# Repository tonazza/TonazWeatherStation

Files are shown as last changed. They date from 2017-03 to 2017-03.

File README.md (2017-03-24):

# TonazWeatherStation
Indoor weather station based on Raspberry Pi 2 model B

**2017/3/24**

Initial upload of the files.
Still NOT working, just a work in progress.

**PROJECT DESCRIPTION**

This is a Weather Station, conceived for measuring air properties in an indoor environment.

The main components are:

**Raspberry Pi 2 Model B** Single board computer

https://www.raspberrypi.org/products/raspberry-pi-2-model-b/

**MIDAS MC21605G12W-VNMLWI** LCD 16x2 chars I2C module, white on black

http://it.farnell.com/midas/mc21605g12w-vnmlwi/lcd-alpha-num-16-x-2-white/dp/2425704

**HONEYWELL HIH8131-000-001** humidity and temperature sensor

http://www.mouser.it/Search/ProductDetail.aspx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

**MEASUREMENT SPECIALTIES MS580502BA01-50** barometric pressure sensor

http://www.mouser.it/Search/ProductDetail.aspx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

The hardware project(Pi HAT + connection boards) was made using EAGLE CAD 6.5.

The software was made in Python 3, to be run on the Raspberry Pi equipped with Raspbian minimal on a 4GB uSD card.

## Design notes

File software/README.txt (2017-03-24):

TONAZ_WEATHER_STATION - NEEDED PACKAGES FOR  PYTHON 3 SOFTWARE

sudo apt-get install python3 python3-dev python3-smbus python3-pip i2c-tools python3-spidev
sudo python3 -m pip install RPi.GPIO

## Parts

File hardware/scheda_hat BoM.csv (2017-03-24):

Part | Value | Device | Package | Description | 3D_PACKAGE | DESCRIPTION | HEIGHT | MANUFACTURER_NAME | MANUFACTURER_PART_NUMBER | MF | MPN | OC_FARNELL | OC_NEWARK | PACKAGE | RS_PART_NUMBER | SUPPLIER | SUPPLIER_NAME
C1 | 100n | C-EUC0805K | C0805K | CAPACITOR, European symbol
C2 | 1u | C-EUC0805K | C0805K | CAPACITOR, European symbol
C3 | 100n | C-EUC0805K | C0805K | CAPACITOR, European symbol
IC1 | HIH8131-000-001 | HIH8131-000-001 | SOIC127P600X220-8N | Honeywell HIH8131-000-001 Humidity Sensor 8-Pin SOIC, -40 +125 C |  | Honeywell HIH8131-000-001 Humidity Sensor 8-Pin SOIC, -40 +125 C | 2.2mm | Honeywell | HIH8131-000-001 |  |  |  |  |  | 8748744 |  | RS
IC2 | MS5805-02BA01 | MS5805-02BA01 | MS5805-02BA | Absolute Pressure Sensor
J3 | LCD MIDAS MC21605G12W | PINHD-1X16 | 1X16 | PIN HEADER
Q1 | FDN337N | FDN337N | SOT95P230X110-3N | N-channel MOSFET |  |  |  |  |  |  | FDN337N | 9845356 |  | SOT-23 |  | Fairchild
Q2 | FDN337N | FDN337N | SOT95P230X110-3N | N-channel MOSFET |  |  |  |  |  |  | FDN337N | 9845356 |  | SOT-23 |  | Fairchild
R1 | 10K | R-EU_R3216 | R3216 | RESISTOR, European symbol
R2 | 10K | R-EU_R3216 | R3216 | RESISTOR, European symbol
R3 | 2K2 | R-EU_R3216 | R3216 | RESISTOR, European symbol
R4 | 2K2 | R-EU_R3216 | R3216 | RESISTOR, European symbol
R5 | 10K | R-EU_R3216 | R3216 | RESISTOR, European symbol
RV1 | 10K | TRIM_EU-CA9V | CA9V | POTENTIOMETER
SV1 | IDC10 90° | ML10L | ML10L | HARTING |  |  |  |  |  |  |  | unknown | unknown
SV2 | IDC10 | ML10 | ML10 | HARTING |  |  |  |  |  |  |  | unknown | unknown
SV3 | IDC16 90° | ML16L | ML16L | HARTING |  |  |  |  |  |  |  | unknown | unknown
SV4 | IDC16 90° | ML16L | ML16L | HARTING |  |  |  |  |  |  |  | unknown | unknown
X1 | RASPI_BOARD_B+_H | RASPI_BOARD_B+_H | RASPI_BOARD_B+HAT | Raspberry Pi GPIO connector with markings for the outer dimensions of the Raspberry Pi board model B+

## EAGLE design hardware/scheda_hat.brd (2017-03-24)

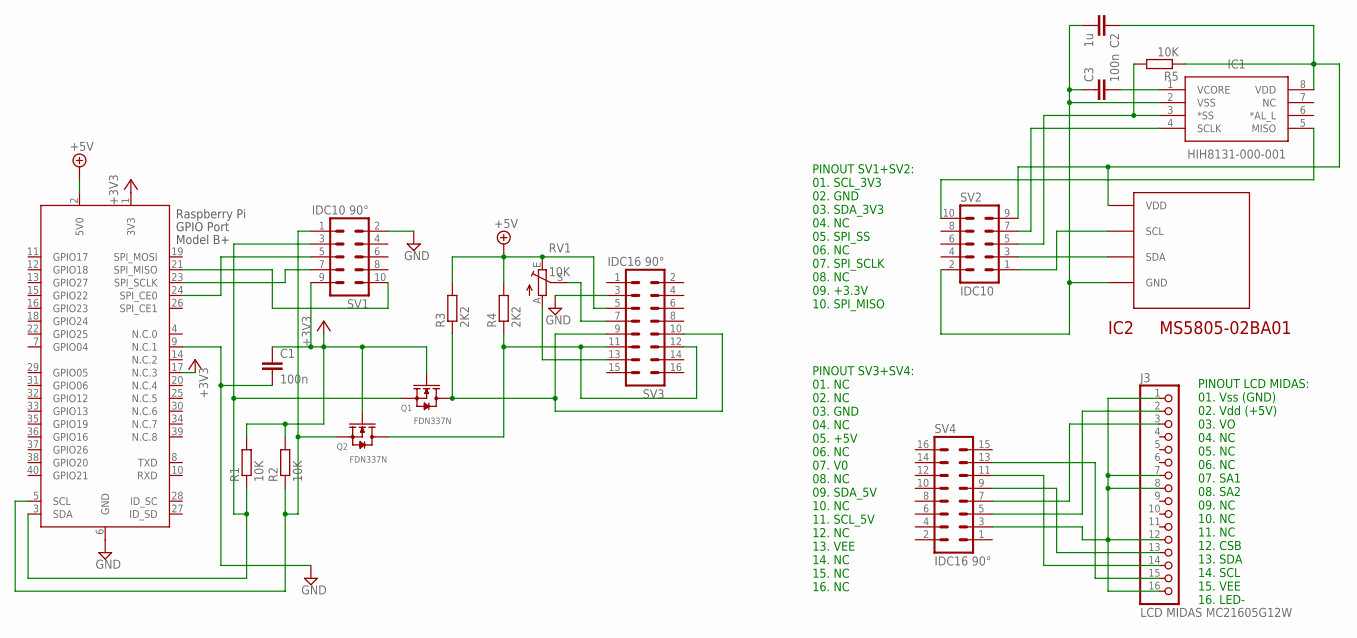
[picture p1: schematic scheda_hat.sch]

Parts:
C1, C3: 100n; C0805K
C2: 1u; C0805K
IC1: HIH8131-000-001; SOIC127P600X220-8N
IC2: MS5805-02BA01; MS5805-02BA
J3: LCD MIDAS MC21605G12W; 1X16
Q1, Q2: FDN337N; SOT95P230X110-3N
R1, R2, R5: 10K; R3216
R3, R4: 2K2; R3216
RV1: 10K; CA9V
SV1: IDC10 90°; ML10L
SV2: IDC10; ML10
SV3, SV4: IDC16 90°; ML16L
X1: RASPI_BOARD_B+_H; RASPI_BOARD_B+HAT

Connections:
+3V3: C1.1, Q1.1 (G1), Q2.1 (G1), R1.2, R2.2, SV1.9, X1.1 (3V3), X1.17 (N.C.3)
+5V: R3.2, R4.2, RV1.E, SV3.5, X1.2 (5V0)
GND: C1.2, SV1.2, SV3.3, X1.6 (GND), X1.9 (N.C.1)
unnamed: IC1.3 (*SS), R5.2, SV2.5
unnamed: J3.1, J3.7, J3.8, J3.12, J3.16, SV4.3
unnamed: RV1.A, SV3.13
unnamed: J3.15, SV4.13
unnamed: C2.2, C3.1, IC1.2 (VSS), IC2.P$4 (GND), SV2.2
unnamed: IC2.P$2 (SCL), SV2.1
unnamed: IC2.P$3 (SDA), SV2.3
unnamed: J3.2, SV4.5
unnamed: IC1.5 (MISO), SV2.10
unnamed: IC1.4 (SCLK), SV2.7
unnamed: J3.3, SV4.7
unnamed: J3.13, SV4.9
unnamed: J3.14, SV4.11
unnamed: C2.1, IC1.8 (VDD), IC2.P$1 (VDD), R5.1, SV2.9
SCL_3V3: Q2.2 (S1), R2.1, SV1.1, X1.5 (SCL)
SCL_5V: Q2.3 (D1), R4.1, SV3.11, SV3.12
SDA_3V3: Q1.2 (S1), R1.1, SV1.3, X1.3 (SDA)
SDA_5V: Q1.3 (D1), R3.1, SV3.9, SV3.10
SPI_MISO: SV1.10, X1.21 (SPI_MISO)
SPI_SCLK: SV1.7, X1.23 (SPI_SCLK)
SPI_SS: SV1.5, X1.24 (SPI_CE0)
V0: RV1.S, SV3.7
VCORE: C3.2, IC1.1 (VCORE)

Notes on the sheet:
PINOUT LCD MIDAS: 01. Vss (GND) 02. Vdd (+5V) 03. VO 04. NC 05. NC 06. NC 07. SA1 08. SA2 09. NC 10. NC 11. NC 12. CSB 13. SDA 14. SCL 15. VEE 16. LED-
PINOUT SV1+SV2: 01. SCL_3V3 02. GND 03. SDA_3V3 04. NC 05. SPI_SS 06. NC 07. SPI_SCLK 08. NC 09. +3.3V 10. SPI_MISO
PINOUT SV3+SV4: 01. NC 02. NC 03. GND 04. NC 05. +5V 06. NC 07. V0 08. NC 09. SDA_5V 10. NC 11. SCL_5V 12. NC 13. VEE 14. NC 15. NC 16. NC

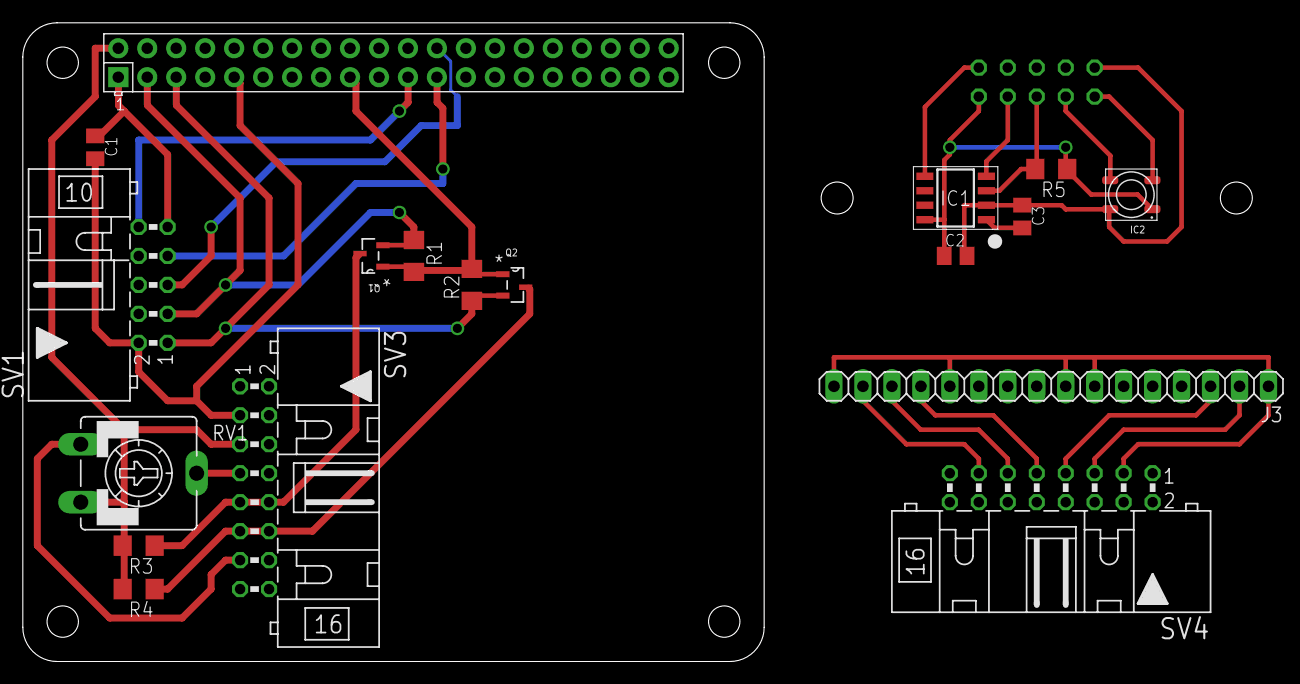
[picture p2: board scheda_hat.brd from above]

Board: 2 copper layers, 65.0 x 56.0 mm, 19 parts (1 on the bottom side), 26 nets.

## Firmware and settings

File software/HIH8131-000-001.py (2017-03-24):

import spidev
import time


spi = spidev.SpiDev() # create spi object
spi.open(0, 0) # open spi port 0, device (CS) 0

try:
    while True:
        risposta= spi.readbytes(1)
        time.sleep(0.2)
        risposta= spi.readbytes(4)
        if (risposta[0]<64) :
            lettura_rh=risposta[1]+256*risposta[0]
            lettura_T=int(risposta[3]/4)+risposta[2]*64
        else:
            lettura_rh=0
            lettura_T=0
         #end if   
        rh= round(lettura_rh*100/16382, 1)
        T= round(-40+lettura_T*165/16382, 1)
        print ("{}% {}°C".format(rh, T))
        time.sleep(0.8) # sleep 
    #end while
except KeyboardInterrupt: # Ctrl+C pressed, so…
    spi.close() # … close the port before exit
#end try

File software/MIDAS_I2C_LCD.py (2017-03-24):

# -*- coding: utf-8 -*-
#!/usr/bin/python
"""
#created by Tonazza for display MIDAS MC21605G12W-VNMLWI
# 2017-03-08
"""

# i2c bus (0 -- original Pi, 1 -- Rev 2 Pi)
I2CBUS = 1

# LCD Address
#ADDRESS = 0x78
ADDRESS = 0x3C

#delay between commands
CMD_DELAY=0.0002

""""
# COMANDI COMPLETI

LCD_CLEARDISPLAY = 0x01

LCD_RETURNHOME = 0x02

LCD_ENTRYMODESET = 0x04
# flags for display entry mode
LCD_ENTRY_INCREMENT_SHIFT_L = 0x02
LCD_ENTRY_DECREMENT_SHIFT_R = 0x00
LCD_ENTRY_SHIFT = 0x01
LCD_ENTRY_NOSHIFT = 0x00

LCD_DISPLAYCONTROL = 0x08
# flags for display on/off control
LCD_DISPLAYON = 0x04
LCD_DISPLAYOFF = 0x00
LCD_CURSORON = 0x02
LCD_CURSOROFF = 0x00
LCD_BLINKON = 0x01
LCD_BLINKOFF = 0x00

LCD_CURSORSHIFT = 0x10
# flags for display/cursor shift
LCD_DISPLAYSHIFT = 0x08
LCD_CURSORSHIFT = 0x00
LCD_SHIFTRIGHT = 0x04
LCD_SHIFTLEFT = 0x00

LCD_FUNCTIONSET = 0x20
# flags for function set
LCD_8BITMODE = 0x10
LCD_4BITMODE = 0x00
LCD_2LINE = 0x08
LCD_1LINE = 0x00
LCD_5x11DOTS = 0x04
LCD_5x8DOTS = 0x00

LCD_SETCGRAMADDR = 0x40

LCD_SETDDRAMADDR = 0x80

"""

# comandi rapidi
CMD_CLEAR_DISPLAY = 0x01
CMD_RETURNHOME = 0x02
CMD_FUNCTION_SET_INIZIALE = 0x38
CMD_CURSOR_SHIFT_RIGHT = 0x14
CMD_DISPLAY_ON = 0x0C

REGMODE1 = 0x00 #preambolo per i comandi
CHARMODE = 0x40 #preambolo per i caratteri

import smbus
from time import sleep

bus = smbus.SMBus(I2CBUS)    # 0 = /dev/i2c-0 (port I2C0), 1 = /dev/i2c-1 (port I2C1)

def LCD_DDRAM_ADDRESS(line=1, pos=0):
    if line == 1:
      pos_new = pos
    elif line == 2:
      pos_new = 0x40 + pos
    return (0x80 + pos_new)

def scrivi_comando(comando):
    bus.write_byte_data(ADDRESS, REGMODE1, comando)
    sleep(CMD_DELAY)

def scrivi_carattere(carattere):
    bus.write_byte_data(ADDRESS, CHARMODE, carattere)
    sleep(CMD_DELAY)

def posiziona_cursore(riga, colonna):
    scrivi_comando(LCD_DDRAM_ADDRESS(riga, colonna-1))
    
def scrivi_stringa(stringa):
    for char in stringa:
      scrivi_carattere(ord(char))
      
def inizializza():
    scrivi_comando(CMD_FUNCTION_SET_INIZIALE)
    scrivi_comando(CMD_CURSOR_SHIFT_RIGHT)
    scrivi_comando(CMD_DISPLAY_ON)
    scrivi_comando(CMD_CLEAR_DISPLAY)
    posiziona_cursore(1, 1)

#test del display

inizializza()
scrivi_stringa("...finalmente...")
posiziona_cursore(2, 1)
scrivi_stringa("...FUNZIONA!!!!!")
